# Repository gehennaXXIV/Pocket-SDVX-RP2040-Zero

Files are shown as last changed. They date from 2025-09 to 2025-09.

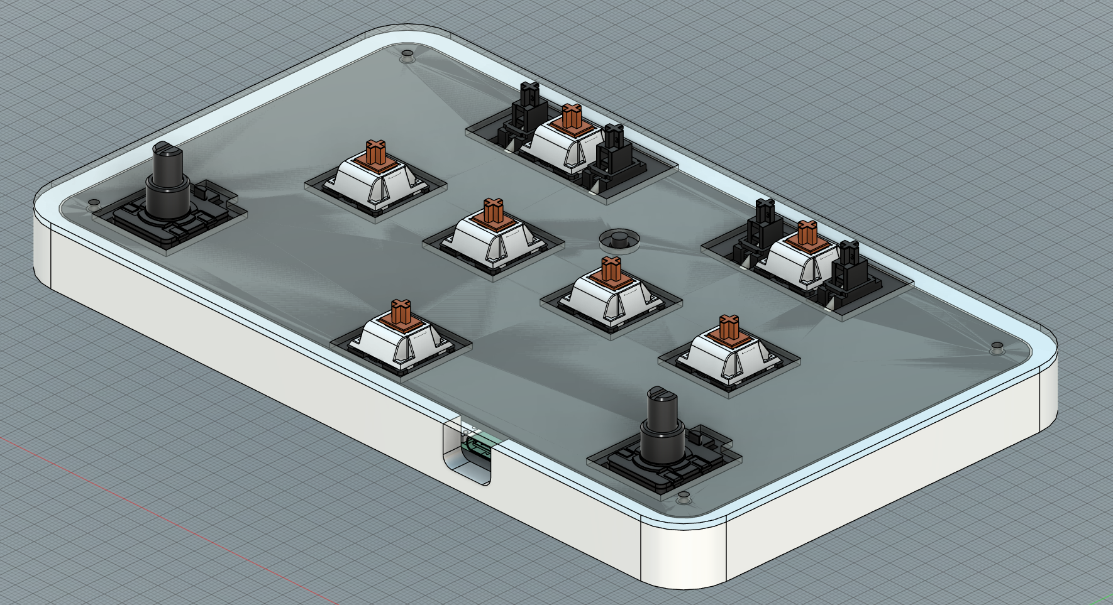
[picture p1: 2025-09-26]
pics/case.png

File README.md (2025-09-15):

# WIP
# Pocket-SDVX-RP2040-Zero

This work is licensed under a Creative Commons Attribution-NonCommercial-ShareAlike 4.0 International License.  中国人，我在看你们。

Pocket SDVX RP2040 Zero v1

## Parts Required:
- JLCPCB parts (Boards are 180 mm*100 mm, white PCB color, remove order number[specify a location]):
    - 1x Pocket-SDVX-RP2040-Zero-Plate-2 (MOQ 5)
    - 1x Pocket-SDVX-RP2040-Zero (MOQ 5)
- McMaster parts:
    - 4x Feet - 8884T13
    - 4x M3 Lock Nut - 90576A102
    - 4x M3x12 Screw - 92095A183 
    - 4x No.6 1/8" Nylon Spacer - 94639A507 
- Mouser parts:
    - 2x 2U PCB Mount stabilizers
    - 2x Encoder - PEC16-4015F-N0024
- 1x RP2040 Zero
- XDA Keycap Set https://www.speedylabs.us/product/pocket-sdvx-keycaps/
    - 1x 1u, 4x 1.5u, 2x 2u
- 2x 22mm Knob https://www.speedylabs.us/product/pocket-sdvx-aluminum-knob/
- 7x Gateron Yellow Switches
- 7x Gateron Hotswap Sockets
- 1x 3D printed case, White PETG https://www.speedylabs.us/product/pocket-sdvx-pico-case/

[Pocket SDVX Pico v4 Quick Start Guide](https://docs.google.com/document/d/1lTzADQI5E5vRpHBv-0IfLbDSh2zEKCUAdh5BqFhex2I/edit?usp=sharing)  
[Kit Assembly Guide](https://docs.google.com/document/d/1bsWk7fmLKUGv5YgQknoNQcy0RX3fi5gCZRvfOJAa-P0/)

## Addendum
As promised many months ago, Speedy Labs' most popular product is now open sourced.  Pocket-SDVX-Pico v4 is my second PCB, and therefore everything's a little bit sloppy.  Nevertheless, everything here is functional and has been self-learned online along with the help of the community.  Thanks for all the support!

FYI I should probably let everyone know the most common defects I've received:
- RGB LEDs dead or not soldered properly
- Extra Aux Button wobbly/non-functional/misaligned
- Smudged Silkscreen

There's probably a 5% chance of this happening according to my statistics.  Nothing you can do about it aside from repairing it yourself.

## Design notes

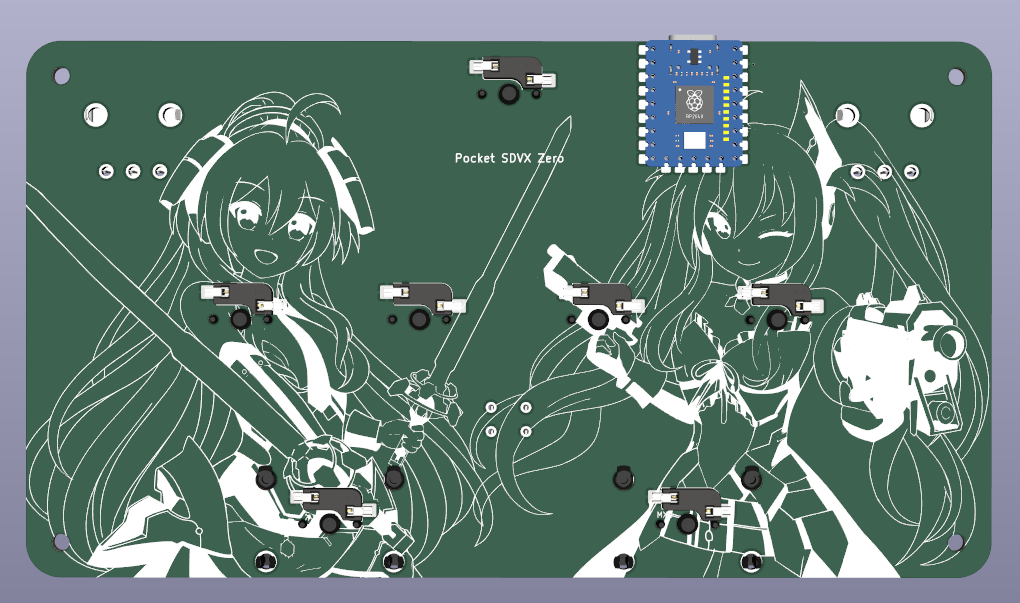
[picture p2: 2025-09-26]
pics/bottom.png

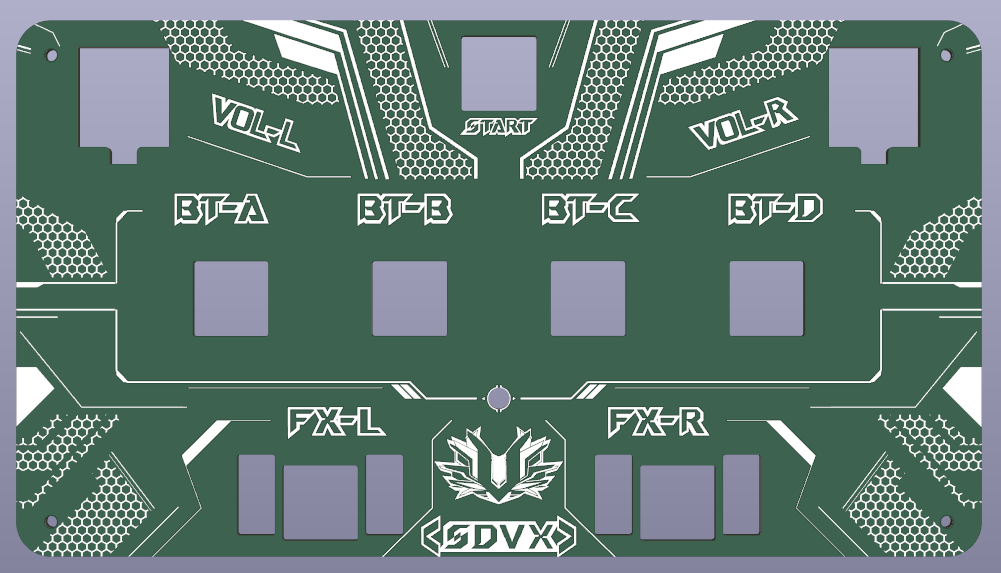
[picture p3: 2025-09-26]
pics/plate.png

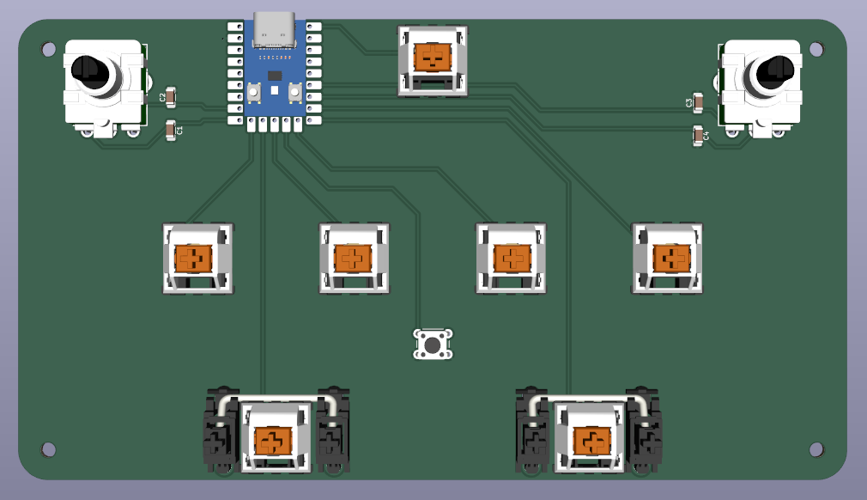
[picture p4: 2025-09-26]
pics/top.png

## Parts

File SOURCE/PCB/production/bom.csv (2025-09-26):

Designator | Footprint | Quantity | Value | LCSC Part #
C1, C2, C3, C4 | 1206 | 4 | 10nF | C57112
E1, E2 | PEC16-4015F-N0024-millmax | 2 | PEC16-4015F-N0024
MX1 | SW_MX_HS_CPG151101S11_1u | 1 | MX-LED-B | C440444
MX2, MX3, MX4, MX5 | SW_MX_HS_CPG151101S11_1.5u | 4 | MX-LED | C26545
MX6, MX7 | SW_MX_HS_CPG151101S11_1u | 2 | MX-LED-R | C440441
S1, S2 | STAB_MX_P_2u | 2 | MX_stab
SW1 | SW_PUSH_6mm_H5mm | 1 | SW_Push
U2 | RP2040_Zero | 1 | RP2040_Zero

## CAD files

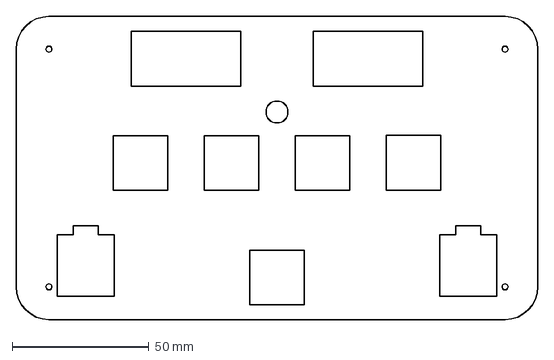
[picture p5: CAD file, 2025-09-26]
PRODUCTION/topcutout.dxf
191.0 x 111.0 mm

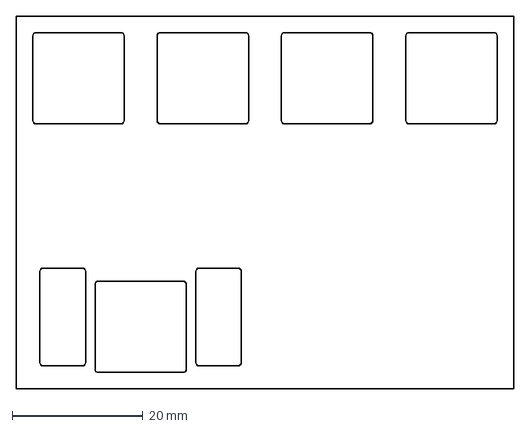
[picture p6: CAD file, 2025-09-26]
SOURCE/PLATE/plate-2025-09-15T05_55_29.111Z.dxf
76.2 x 57.1 mm

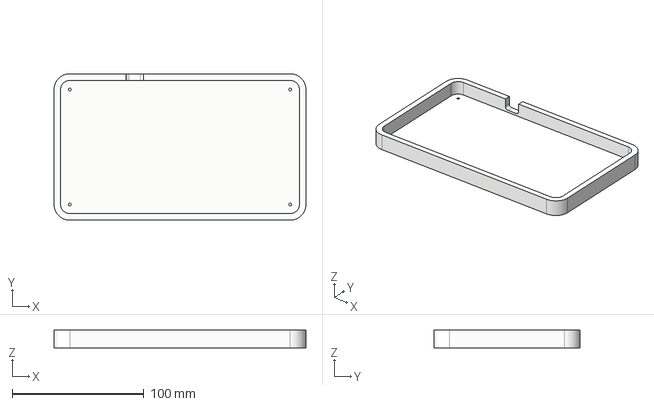
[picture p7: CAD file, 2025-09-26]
PRODUCTION/Pocket-SDVX-RP2040Zero v4.step
191.0 x 111.0 x 13.5 mm

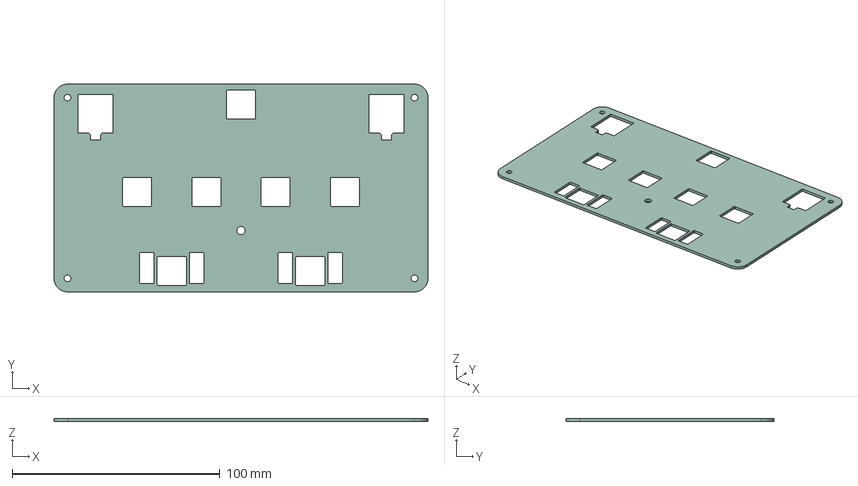
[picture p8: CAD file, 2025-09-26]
SOURCE/PLATE/Pocket-SDVX-RP2040-Zero-Plate.step
180.0 x 100.0 x 1.51 mm

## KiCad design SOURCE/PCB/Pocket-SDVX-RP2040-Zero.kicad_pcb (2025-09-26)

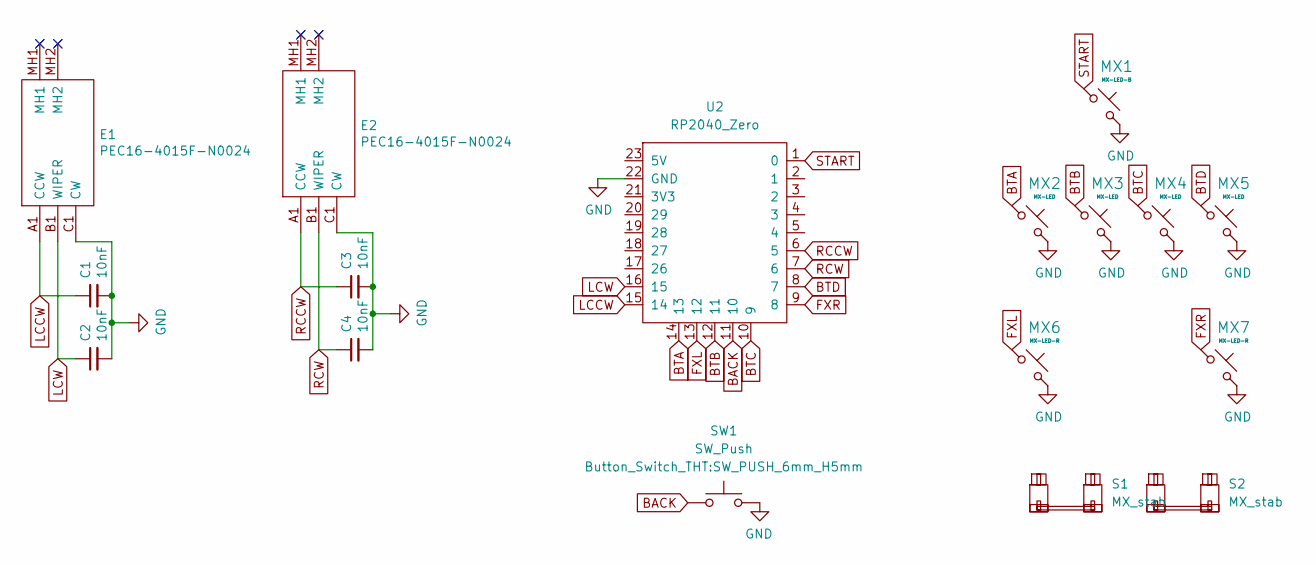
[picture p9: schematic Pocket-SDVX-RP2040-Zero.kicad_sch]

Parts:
C1, C2, C3, C4: 10nF; C_1206_3216Metric_Pad1.33x1.80mm_HandSolder; LCSC C57112
E1, E2: PEC16-4015F-N0024; PEC16-4015F-N0024-millmax; Mouser Part Number 652-PEC16-4015FN0024
MX1: MX-LED-B; SW_MX_HS_CPG151101S11_1u; LCSC C440444
MX2, MX3, MX4, MX5: MX-LED; SW_MX_HS_CPG151101S11_1.5u; LCSC C26545
MX6, MX7: MX-LED-R; SW_MX_HS_CPG151101S11_1u; LCSC C440441
S1, S2: MX_stab; STAB_MX_P_2u
SW1: SW_Push; SW_PUSH_6mm_H5mm
U2: RP2040_Zero

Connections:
BACK: SW1.1, U2.11 (10)
BTA: MX2.1, U2.14 (13)
BTB: MX3.1, U2.12 (11)
BTC: MX4.1, U2.10 (9)
BTD: MX5.1, U2.8 (7)
FXL: MX6.1, U2.13 (12)
FXR: MX7.1, U2.9 (8)
GND: C1.2, C2.2, C3.2, C4.2, E1.C1 (CW), E2.C1 (CW), MX1.2, MX2.2, MX3.2, MX4.2, MX5.2, MX6.2, MX7.2, SW1.2, U2.22 (GND)
LCCW: C1.1, E1.A1 (CCW), U2.15 (14)
LCW: C2.1, E1.B1 (WIPER), U2.16 (15)
RCCW: C3.1, E2.A1 (CCW), U2.6 (5)
RCW: C4.1, E2.B1 (WIPER), U2.7 (6)
START: MX1.1, U2.1 (0)

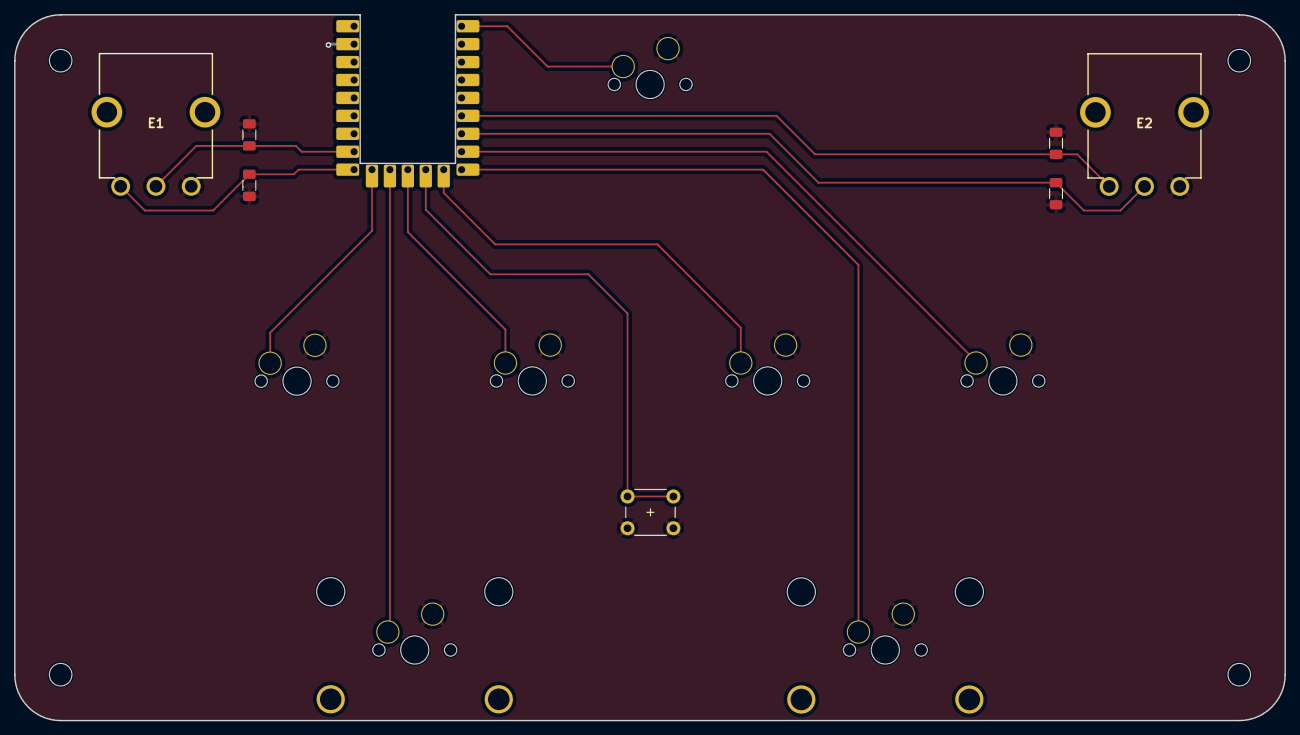
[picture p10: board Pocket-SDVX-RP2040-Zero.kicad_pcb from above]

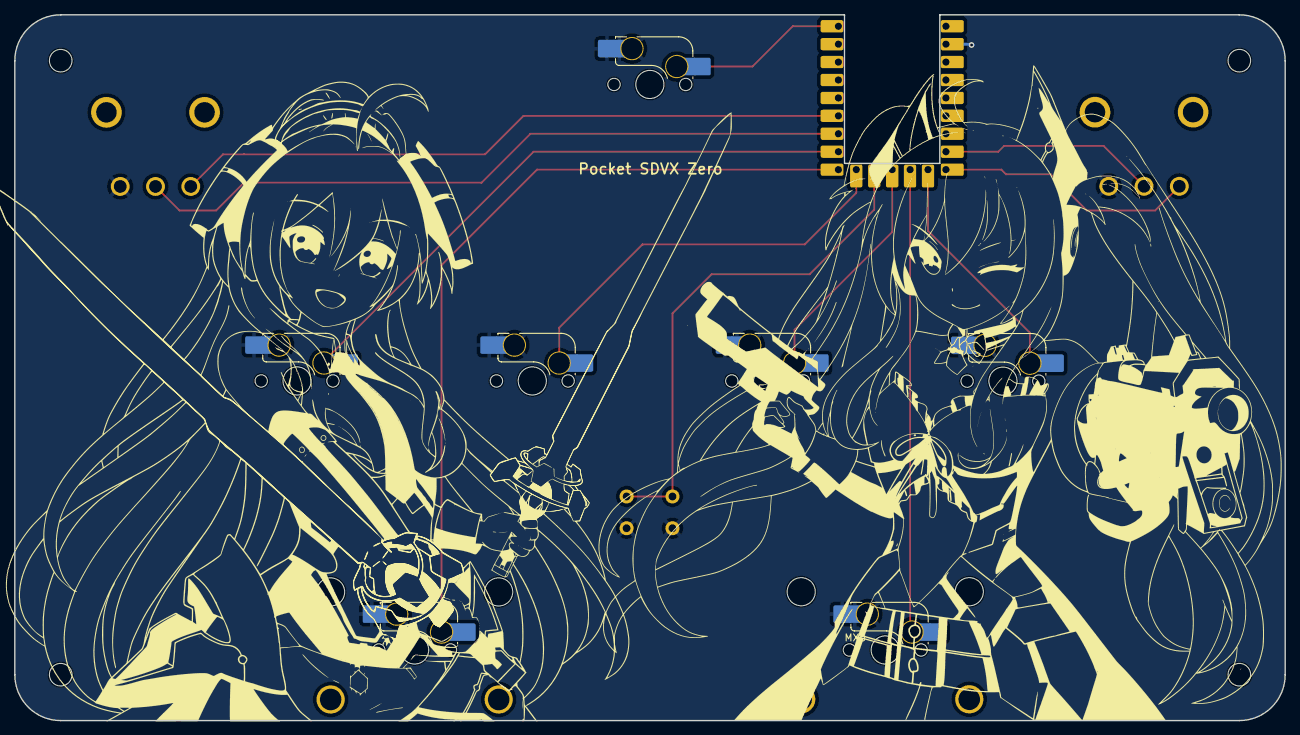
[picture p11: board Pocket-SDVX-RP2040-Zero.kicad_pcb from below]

Board: 2 copper layers, 180.0 x 100.0 mm, 17 parts (7 on the bottom side), 13 nets.
